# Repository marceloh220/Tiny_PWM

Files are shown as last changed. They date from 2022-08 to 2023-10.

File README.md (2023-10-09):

# Tiny_PWM
Dual channel PWM driver controller. For LEDs, motors and other strangers things.\
Based on Attiny25/45/85 microcontroller this device have two PWM channels controlled by independent potentiometer.

Fusebits:
  - Low:      0x62
  - High:     0xDC
  - Extended: 0xFF

Install avr-gcc:

 - windows:
    
       https://blog.zakkemble.net/avr-gcc-builds/
    
   Include the bin directory on system path
    
 -  Debian/Ubuntu:
    
        sudo apt install gcc-avr avr-libc binutils-avr
   
  - RedHat/Fedora:
    
        sudo dnf install avr-gcc avr-libc avr-binutils
    
  - Arch/Manjaro:
    
        sudo pacman -S avr-gcc avr-libc avr-binutils

Install avrdude:

  - Windows:

    Avrdude comes with avr-gcc
   
  - Debian/Ubuntu:
    
        sudo apt install avrdude
   
  - RedHat/Fedora:
    
        sudo dnf install avrdude
    
  - Arch/Manjaro:
    
        sudo pacman -S avrdude

Install Make:
    
  - Windows:
   
    Make comes with avr-gcc
    
   - Debian/Ubuntu:
   
    sudo apt install make
   
   - RedHat/Fedora:
   
    sudo dnf install make
   
   - Arch/Manjaro:
   
    sudo pacman -S make

Using:
  
   - Generate executable .elf files
     
         make all
         
   - Generate .hex files
   
         make hex
   
   - Clean build
        
         make clean
         
   - Verify size program
   
         make size
     
   - Configure fusebits
       
         make fuses
       
   - Upload to device

         make program

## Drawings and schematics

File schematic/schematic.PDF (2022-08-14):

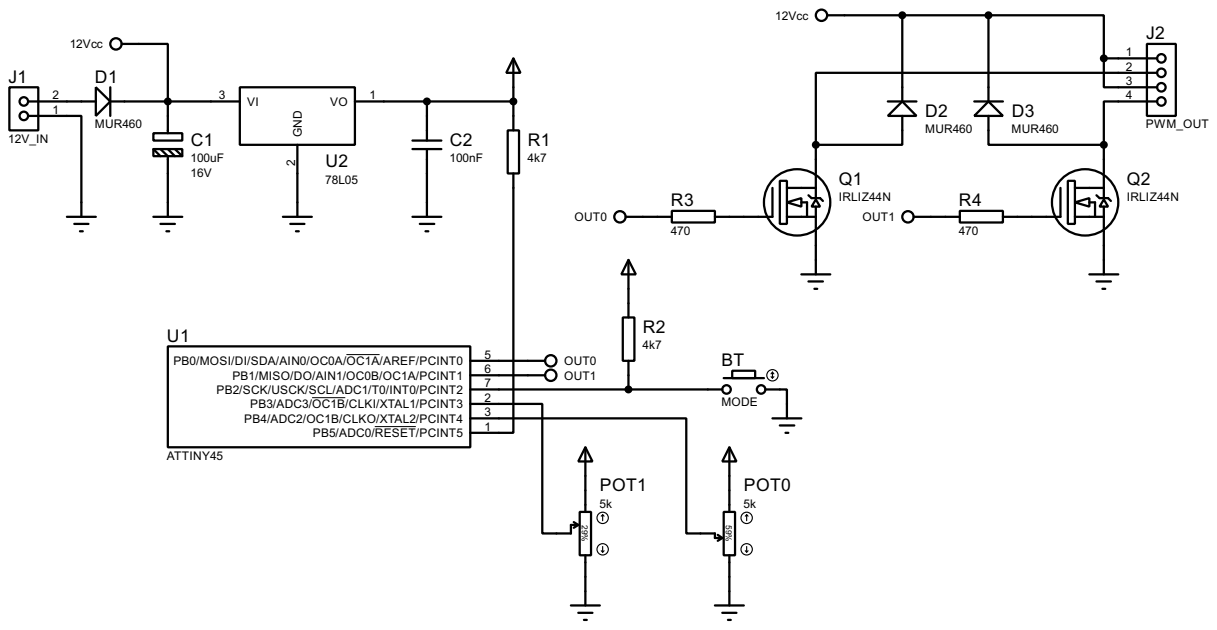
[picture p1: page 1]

6 PB0/MOSI/DI/SDA/AIN0/OC0A/OC1A/AREF/PCINT0

3 PB2/SCK/USCK/SCL/ADC1/T0/INT0/PCINT2
2 PB4/ADC2/OC1B/CLKO/XTAL2/PCINT4 1 PB3/ADC3/OC1B/CLKI/XTAL1/PCINT3

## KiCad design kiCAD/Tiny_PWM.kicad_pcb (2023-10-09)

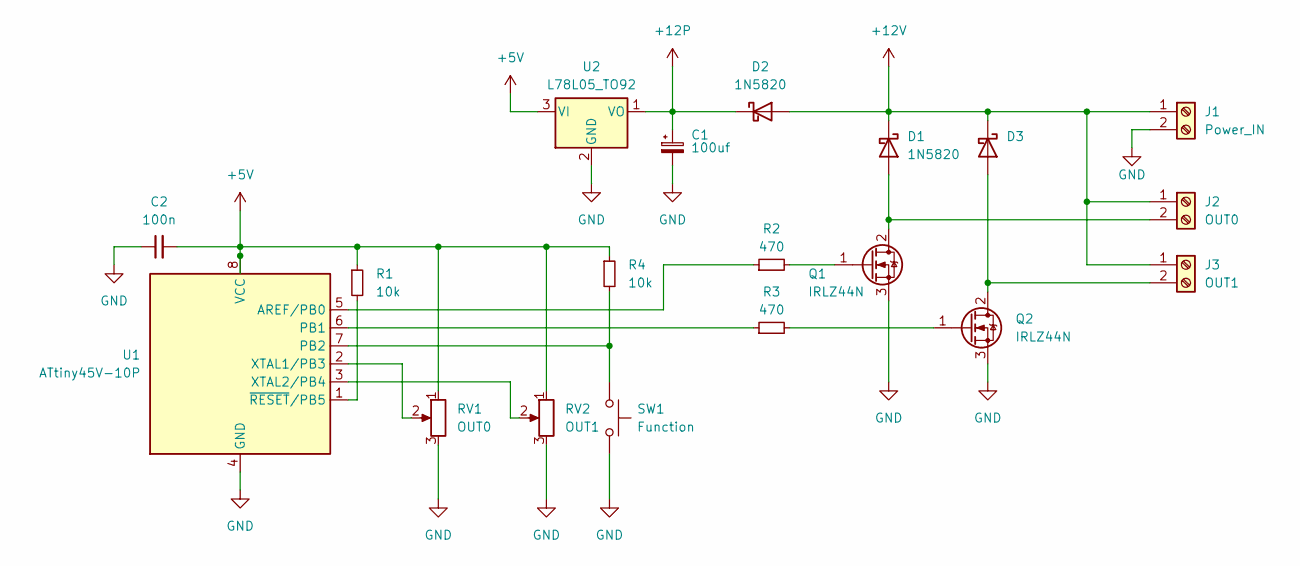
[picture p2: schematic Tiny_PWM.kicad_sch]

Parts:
C1: 100uf; CP_Radial_D6.3mm_P2.50mm
C2: 100n; C_Disc_D5.0mm_W2.5mm_P2.50mm
D1, D2, D3: 1N5820; D_DO-34_SOD68_P7.62mm_Horizontal
J1: Power_IN; TerminalBlock_Altech_AK300-2_P5.00mm
J2: OUT0; TerminalBlock_Altech_AK300-2_P5.00mm
J3: OUT1; TerminalBlock_Altech_AK300-2_P5.00mm
Q1, Q2: IRLZ44N; TO-220-3_Vertical
R1, R4: 10k; R_Axial_DIN0204_L3.6mm_D1.6mm_P7.62mm_Horizontal
R2, R3: 470; R_Axial_DIN0204_L3.6mm_D1.6mm_P7.62mm_Horizontal
RV1: OUT0; Potentiometer_Alps_RK163_Single_Horizontal
RV2: OUT1; Potentiometer_Alps_RK163_Single_Horizontal
SW1: Function; SW_PUSH_6mm
U1: ATtiny45V-10P; DIP-8_W7.62mm
U2: L78L05_TO92; TO-92_Inline

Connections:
+5V: C2.2, R1.1, R4.1, RV1.1, RV2.1, U1.8 (VCC), U2.3 (VI)
+12P: C1.1, D2.1 (K), U2.1 (VO)
+12V: D1.1 (K), D2.2 (A), D3.1 (K), J1.1, J2.1, J3.1
GND: C1.2, C2.1, J1.2, Q1.3 (S), Q2.3 (S), RV1.3, RV2.3, SW1.2, U1.4 (GND), U2.2 (GND)
unnamed: D1.2 (A), J2.2, Q1.2 (D)
unnamed: D3.2 (A), J3.2, Q2.2 (D)
unnamed: Q1.1 (G), R2.2
unnamed: Q2.1 (G), R3.2
unnamed: R2.1, U1.5 (AREF/PB0)
unnamed: R3.1, U1.6 (PB1)
unnamed: R4.2, SW1.1, U1.7 (PB2)
unnamed: RV1.2, U1.2 (XTAL1/PB3)
unnamed: RV2.2, U1.3 (XTAL2/PB4)
unnamed: R1.2, U1.1 (~RESET/PB5)

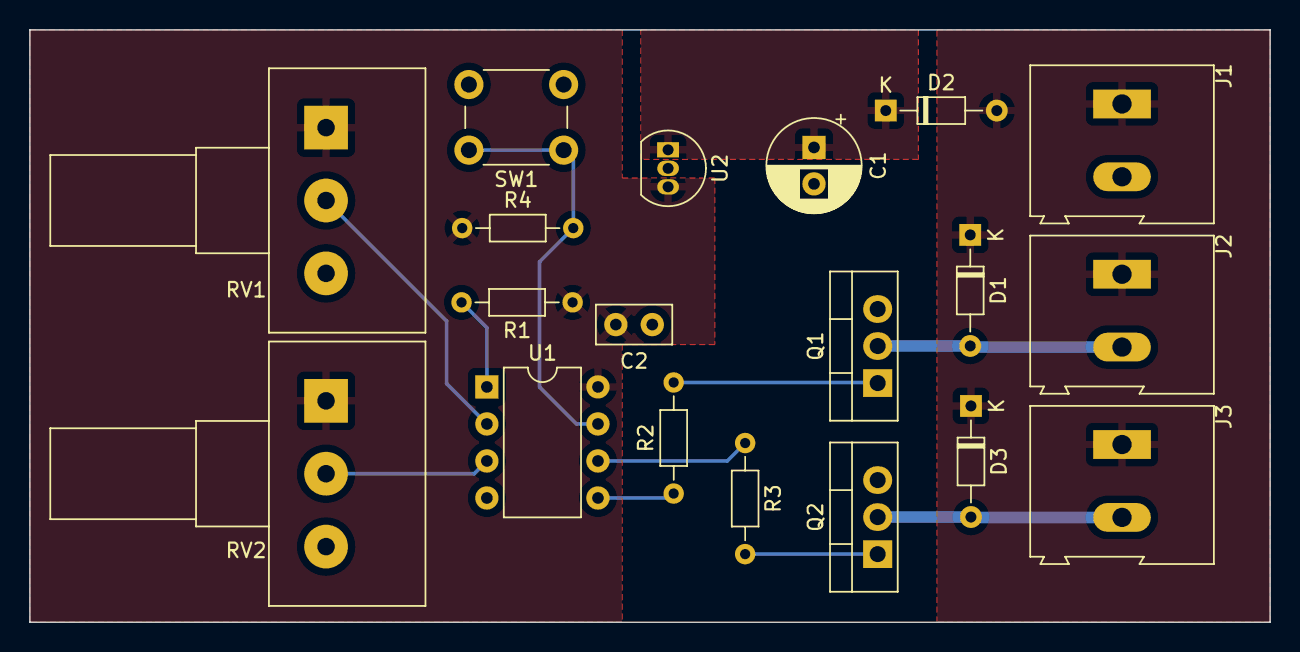
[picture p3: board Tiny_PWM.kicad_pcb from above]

Board: 2 copper layers, 85.1 x 40.6 mm, 19 parts (0 on the bottom side), 14 nets.

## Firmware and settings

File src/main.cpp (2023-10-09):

/*
	controlLED.cpp

	MIT License

	Copyright (c) 2022 Marcelo H Moraes

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
 */ 

#include "defines.h"
#include "power.h"
#include "pwm.h"
#include "adc.h"
#include "button.h"
#include "timer.h"

#ifdef AUTO_TEST
void blink_out() {
	_on(_OUT0);
	_on(_OUT1);
	_delay_ms(500);
	_off(_OUT0);
	_off(_OUT1);
	_delay_ms(500);
}
#endif

int main(void) {
	
	/*configure gpios pins*/
	_pullup(_BT);
	_out(_OUT0);
	_out(_OUT1);
#ifdef AUTO_TEST
	/*test outputs in first power on*/
	for(uint8_t i = 0; i < 3; i++) {
		blink_out();
	}
#endif
	/*initialize peripherals*/
	power_init();
	pwm_init();
	adc_init();
	timer_init();
	//wdt_enable(WDTO_1S);
	system_init();
	
    while (1) {
		
		/*process new sample*/
		adc_sample();
		
		/*pass setpoint to PWM output, shift left by 2 is the same as divide by 4
		  ADC has 10 bits but PWM has only 8, divide by 4 convert this resolution*/
		pwm_out0(adc_read(0)>>2);
#ifdef DUAL_CHANNEL
		pwm_out1(adc_read(1)>>2);
#endif
		
		/*at final of sample processing cpu go to idle mode*/
		power_idle();
		power_wkup();
		
		/*WDT must be reset from time to time*/
		wdt_reset();
    
	}
}

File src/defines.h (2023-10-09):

/*
	defines.h

	MIT License

	Copyright (c) 2022 Marcelo H Moraes

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
	Description:
		Are two channels of PWM control output, each one controlled by a potentiometer
		Are three modes:
			mode 0: The MCU is in power down and outputs is turn off
  			mode 1: Only OUT0 is driven, the OUT1 is turn off
  			mode 2: Only OUT1 is driven, the OUT0 is turn off
  			mode 3(default): Both outputs is driven
  	
  	Identity of system:
  		OUT1: PWM out 0 at PB0 pin
  		OUT2: PWM out 1 at PB1 pin
  		POT1: ADC channel 2 control PWM out at PB4 pin
  		POT2: ADC channel 3 control PWM out at PB3 pin
  		BTN0: INT0 interrupt to wakeup MCU and change modes
  		
  	Peripheral:
  		The clock MCU is running at 1MHz
  		The Brown-down detect programed at 4.5V
  		The PWM is generated by Timer 0 at frequency predefined and calculate by move average with number max of samples defined in NUMBER_OF_SAMPLES
  		Timer 1 generate the times to read the analog inputs with ADC each 16ms and debounce the button at 114ms
  		The ADC read two analog inputs, the ADC complete ISR change between the two channels, each channel have frequency 30 samples/s 
  		The button is read at falling edge by external interrupt INT0, a debounce time of 114ms verify if button is liberated.
  		INT0 wakeup CPU from power down and change PWM mode
        	Sleep Power Down is active in mode 0
  		Sleep IDLE is active in the end of each ADC read, sample process and control read, until the next ADC read time
  
*/
#ifndef DEFINES_H_
#define DEFINES_H_

#include "avr/io.h"
#include "avr/eeprom.h"
#include "avr/interrupt.h"
#include "avr/sleep.h"
#include "avr/wdt.h"
#include "util/delay.h"
#include "inttypes.h"

/****                    Pins configuration                   ****/

#define _OUT0 PB0
#define _OUT1 PB1

#define _OUT0_PWM OCR0A
#define _OUT1_PWM OCR0B

#define _BT	PB2

//#define	BUTTON_ENABLE
//#define	AUTO_TEST
//#define DUAL_CHANNEL

#define _ADC_CH0	2
#define _ADC_CH1	3

/****                    Filter configuration                    ****/

/*	Number of samples in moving average
	More samples means steady and smooth captures, but slower the changes*/
#define NUMBER_OF_SAMPLES		10

// Threshold to PWM out accept variation
#define PWM_OUT_THRESHOLD		5

/****                    PWM configuration                    ****/

/*
	Fclk = 1MHz
	
	PWM Correct Phase mode:
		Fpwm = Fclk / N / 510
		
	PWM Fast mode:
		Fpwm = Fclk / N / 256
	
	Above 300Hz is good for the eyes, but to camera captures needs above 1KHz
	Controlled led must match frequency, using more speed may result in loss of control resolution
	
	Select one mode and prescaler below
	
	Default mode:
		Fpwm = 1E6 / 1 / 510 = 1960 Hz
	
*/

#define PWM_MODE	(_bv(WGM00))				/*Phase Correct PWM*/
//#define PWM_MODE	(_bv(WGM01)|_bv(WGM00))		/*Fast PWM*/

#define PWM_PRESCALE (_bv(CS00))				/*Fclk/1, N = 1*/
//#define PWM_PRESCALE (_bv(CS01))				/*Fclk/8, N = 8 */
//#define PWM_PRESCALE (_bv(CS01)|_bv(CS00))	/*Fclk/64, N = 64*/
//#define PWM_PRESCALE (_bv(CS02))				/*Fclk/256, N = 256*/
//#define PWM_PRESCALE (_bv(CS02)|_bv(CS00))	/*Fclk/1024, N = 1024*/

/****                    Utils Macros                    ****/

#define _bv(_bit)	(1<<_bit)

#define _out(_pin)		{PORTB&=~_bv(_pin); DDRB|=_bv(_pin);}
#define _pullup(_pin)	{DDRB&=~_bv(_pin); PORTB|=_bv(_pin);}

#define _off(_pin)	(PORTB&=~_bv(_pin))
#define _on(_pin)	(PORTB|=_bv(_pin))

#define _read(_pin)	(PINB&_bv(_pin))

#define system_init() {sei();}

#endif /* DEFINES_H_ */

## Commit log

2022-08-14 Add flyback diodes on outputs
2022-08-14 Added more modes to PWM out
    Added PWM PWM Fast and PWM Correct Phase modes
    Frequency output can be calculated using these modes and prescalers
    [defines.h, pwm.cpp]
2023-08-05 kiCAD
    Add schematics and PCI layout with KiCad
    [Tiny_PWM.kicad_pcb, Tiny_PWM.kicad_sch]
2023-10-09 New output filter
    An added output filter method to prevent flickering.
    [Tiny_PWM.kicad_pcb, Tiny_PWM.kicad_sch]
